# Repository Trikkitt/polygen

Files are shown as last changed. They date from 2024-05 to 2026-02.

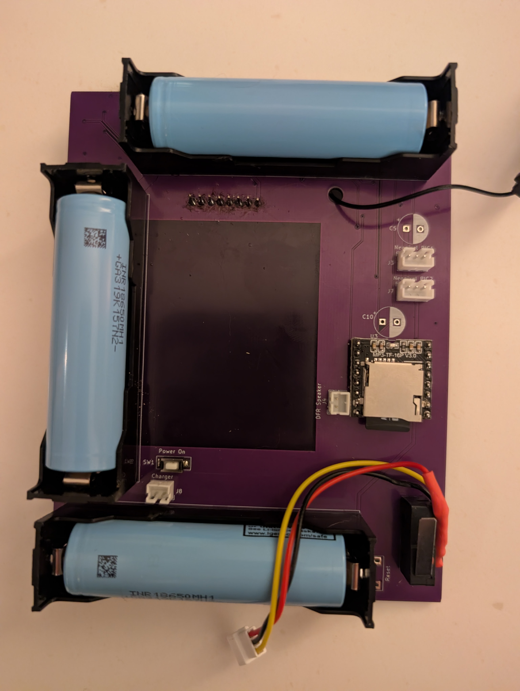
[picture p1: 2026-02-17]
PCB/PCB - Bottom.jpg

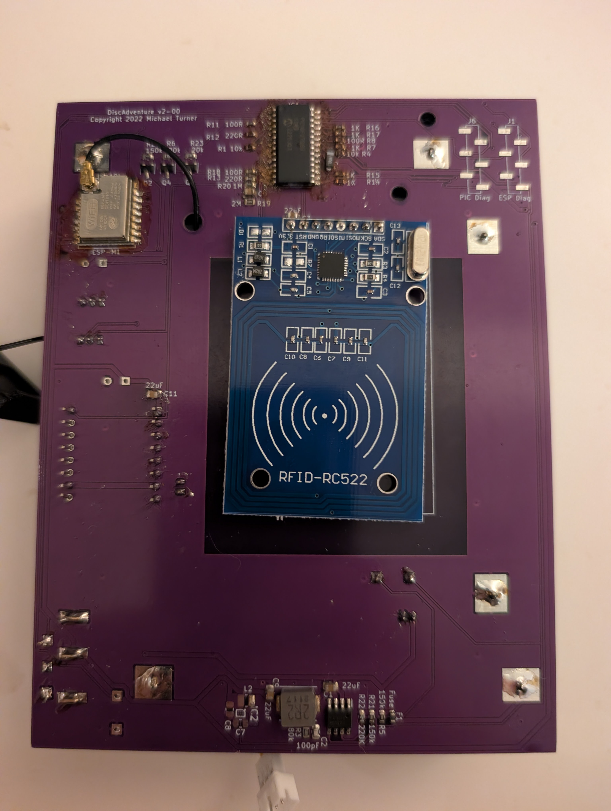
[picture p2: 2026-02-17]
PCB/PCB - Top.jpg

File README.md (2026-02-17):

The folders are as follows:

3D Models : Contains the STL files for the casing and information about the physical assembly
  
PIC : Contains the source code and compiled .HEX file for the PIC Microcontroller used by the game

Micropython : Contains the Micropyhon code used by the ESP8285 used by the game

PCB : Contains the KiCAD PCB design used in each of the game units
  
Game : Contains the primary game code including database

Sounds: The audio files played by the game units, along with some source / raw media.

The 3D model was designed using Tinkercad.  The URL for the 2024 design is https://www.tinkercad.com/things/fUl2xMWVo1S-polygen-case-2024-final and the 2025 design https://www.tinkercad.com/things/fGMrmOF5N9D-polygen-case-2025-final and this repository contains the export STL files from Tinkercad.

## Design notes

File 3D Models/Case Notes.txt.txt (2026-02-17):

The main body of the case can be printed in most materials of your choice.  I've found that Polycarbonate can be strong but will shatter if enough force is used. I don't recommend PLA because that can warp if it gets too warm.  If you're using this at a festival it can get a bit hot.

The clips should be printed in PETG.  This gives them maximum flex without snapping, they cannot be printed in polycarbonate.  Extra bits needed for the cases:

UK 2p coins (magnetic, not the older copper coins).  If you don't have access to these then you might want to consider some large washers and slightly redesigning the clips to hold them.  You could completely ignore the clips, but they really should be used to keep the upper and lower sections at the front pulled together evenly.  You could redesign to just use screws if you wanted to simplify the design.

The V2 case uses M4 threaded inserts.  You'll need 4 per case.  One in the speaker holder/cover, one in the front main body at the top where the reinforcement screws are located, and one on the antenna mount.  You'll need matching M4 bolts 16mm.

The case will print without supports on most 3D printers. Each of the main parts prints with the outward face being downwards.  For my printed I used a textured PEI bed to give it a nice finish.  I used a Bambu X1C for my prints using a multi-filament design.  The logos, URLs, etc are all loaded in separately and then merged within Bambu studio.  

There is an extra tamper switch mount.  This is optional and I haven't used them on any of my units.  It is intended to go into the top left corner of the PCB to provide two detection locations on the PCB.  It isn't really needed but if you're wanting to ensure even if the case is smashed open the tamper detection is triggered, this is the way to go.

If you want to see the finish printed case parts then please look in the assembly folder that will show you the various parts being assembled / pulled apart.

You can look at the original design on this URL.  Feel free to copy and remix it to fix anything you want to change.

https://www.tinkercad.com/things/fGMrmOF5N9D-polygen-case-2025-final

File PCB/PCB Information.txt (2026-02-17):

This PCB was designed in KiCAD and went through a few revisions, in part due to issues with supply on components in 2021/2022.  Most of the parts are readily available still, however you may struggle to find the parts for the 3.3v power supply, these were constantly appearing and dropping out of availability.  The RC522 boards are available but quality of these varies a lot, with some simply not being viable for reading anything other than the most basic MiFare Classic clone cards.  Some details about how to improve some modules is available here https://trikkitt.com/rfid-rc522-rfid-reader-modules-why-they-dont-work-and-how-to-fix-them/ but be aware some are so bad they can't be fixed.  I had to bin around 20 modules as a result.  While it mentioned the DFR299 audio modules there are very cheap clones available that I ended up using to keep costs down.  The tamper switches are optional, if you aren't going to use them either remove the code that monitors them, or link them out.  If you only need one then make sure you link the other one out or you will get problems!

Update from November 2025: The original PIC microcontroller (16LF15356) has run out of capacity as of the code base from mid-2025.  As a result all of my units have been upgraded to use 18F27Q83.  This new PIC has sufficient capacity for future code increases and isn't crazy expensive.  It does consume a little more energy as it isn't the LF version (it just isn't available on this model) and it can run at higher clock speeds. They are pin compatible, so can be used interchangeably if required, but be aware the older one has zero space and has no OTA update code.  While the 18F27Q83 has lots of capacity and the current build does contain a very basic OTA update mechanism.

The power supply chip has gone end of life.  When checking the chip was available from Farnell from limit residual stock.  Before producing these PCBs please ensure you either have purchased the chips required OR redesign the 3.3v power regulation with a new part.  Note it does include two power chips, you need only populate one of them! One turned out to be way too small to be hand soldered and was never populated or tested.  The main things are to check that any replacement supports an enable pin on the chip so that the PIC microcontroller can control the power and turn the unit off if needed.

The tamper detection switches are optional.  But if you don't use them, then be sure to link them out to avoid floating voltages triggering the tamper detection incorrectly.  The pictured tamper detection configuration uses a PCB mounted microswitch to detect removal of the back case, and it also includes a cable run to a microswitch mounted on the back of the case to detect removal of the speaker.  The red heat shrink includes a 10K Ohm resistor just in case of shorts on the microswitch, but it will work without the resistor. If you don't want this secondary switch then just link out the switch connections.

The RC522 RFID reader has the LED removed to save power (it serves no useful purpose), it also has the pullup resistor removed as the PIC always directly drives this pin, therefore there is no benefit to having this resistor and it wastes power.  The inductors are replaced (link to article above) so that it can successfully read more than just the Mifare 1k RFID cards.

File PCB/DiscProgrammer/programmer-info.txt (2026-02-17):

The programmer is a very simple PCB designed to enable connection of either a PICKit3 programmer to the main PCB to programme the PIC microcontroller or a simple 3.3v USB to serial connection for the ESP825 module.

The programmer uses pogo pins to connect to the main PCB.  Be aware that when I made this I used the battery connector to pickup the ground connection on the PCB.  A flooded battery connector can push up the pogo pin so far you don't make good contact on the remaining pins.  These really need a 3D printed case to help home it correctly.

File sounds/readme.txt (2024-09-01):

The sound files in the MP3 folder are the files stored on the MicroSD card inserted into the MP3 player inside each unit.  The file numbers are critical - they must be copied in that exact order as the game references them by index number and not filename.

The sound was generated via a few mechanisms.  The more recent ones are Azure Text to Speech.  While some other TTS services were used for the earlier voices.  The sound effects were generated via various tools and manipulated using Audacity.

https://app.audiogen.co/
https://speech.microsoft.com/portal

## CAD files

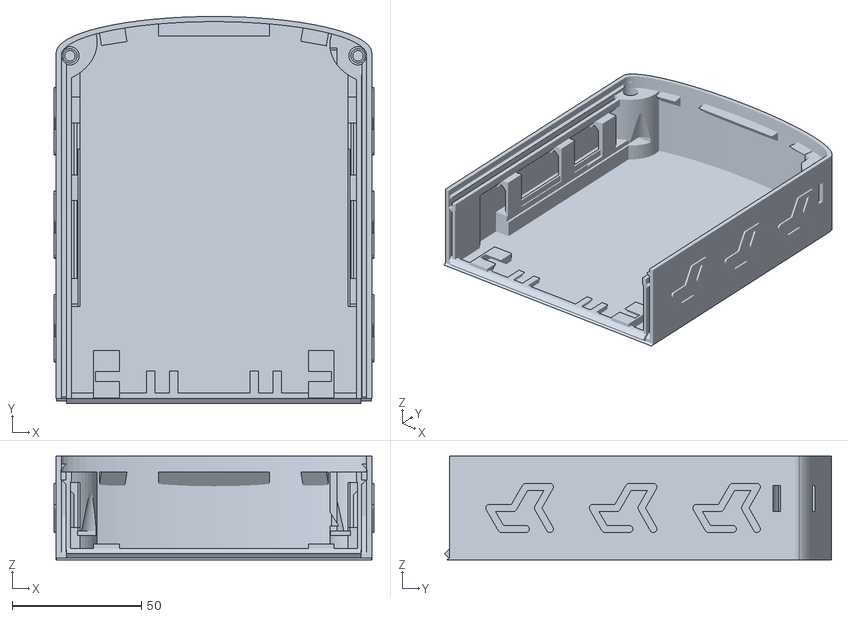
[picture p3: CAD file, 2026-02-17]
3D Models/Case V2/PolyGen Case Main Body.stl
123.7 x 149.6 x 40.0

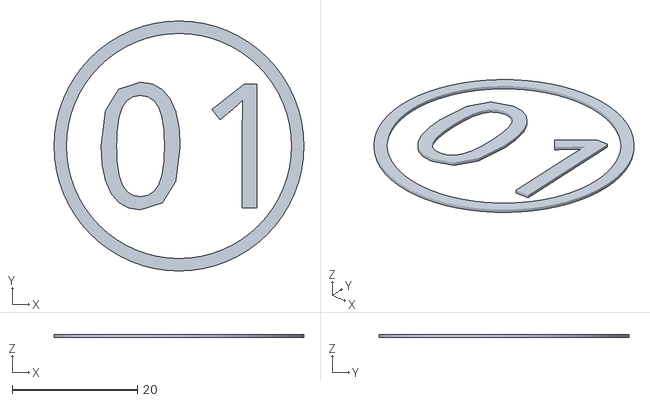
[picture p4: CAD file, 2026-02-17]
3D Models/Case V2/PolyGen Case Back Case ID 01.stl
40.0 x 40.0 x 0.5

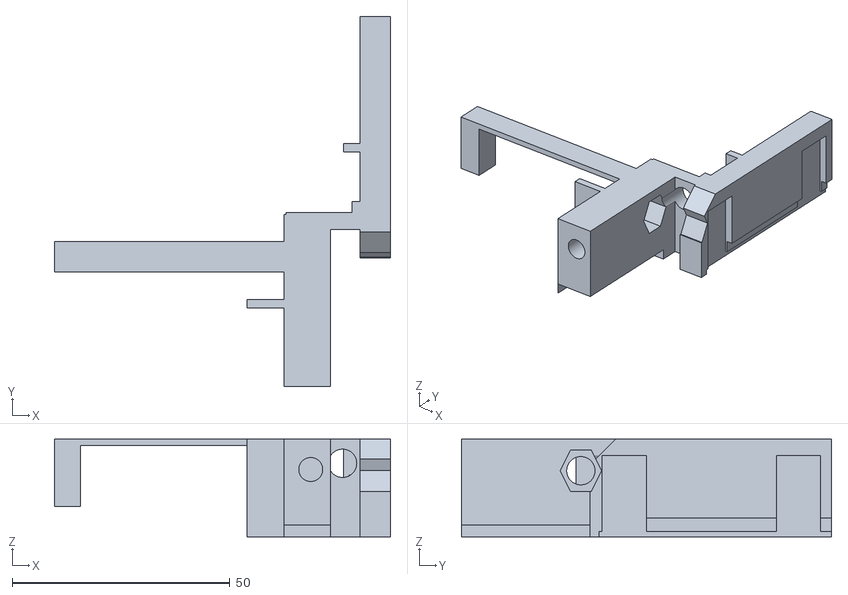
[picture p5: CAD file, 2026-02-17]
3D Models/Case V2/PolyGen Case Antenna Holder.stl
77.2 x 85.0 x 22.5

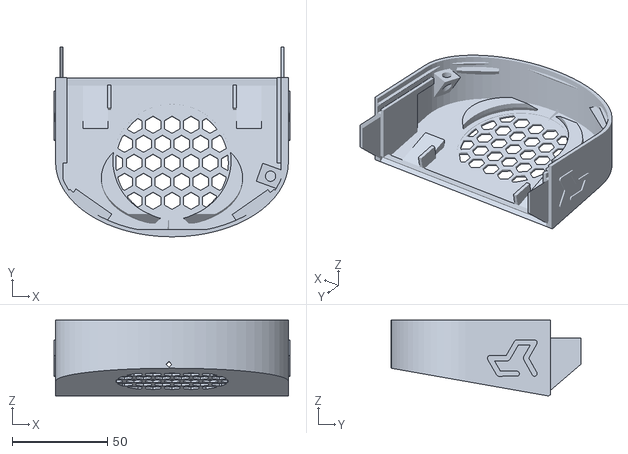
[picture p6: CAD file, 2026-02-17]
3D Models/Case V2/PolyGen Case Front Speaker Cover.stl
123.7 x 99.4 x 39.8

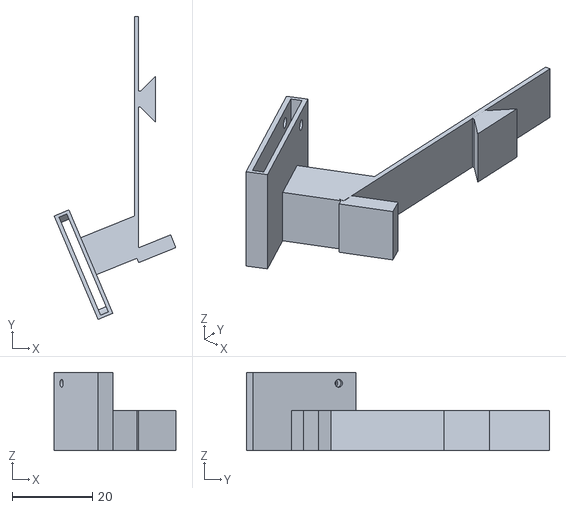
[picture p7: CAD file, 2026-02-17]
3D Models/Case V2/PolyGen Case Left Clip.stl
30.3 x 75.5 x 19.5

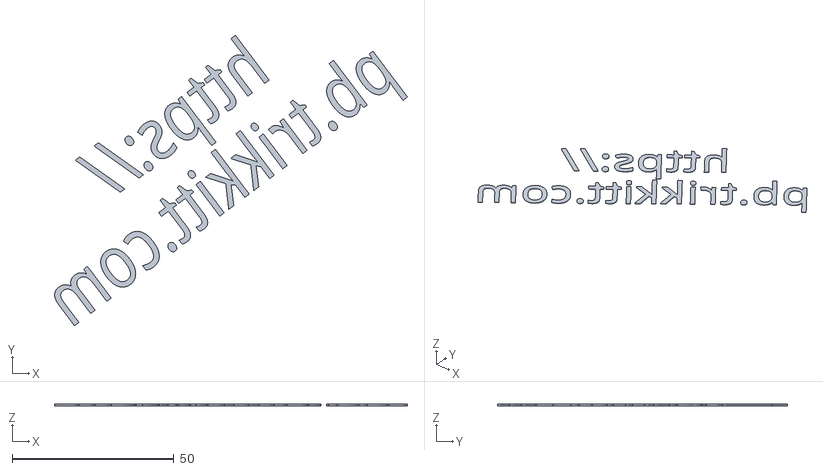
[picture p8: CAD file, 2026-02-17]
3D Models/Case V2/PolyGen Case Back URL.stl
109.0 x 89.7 x 0.5

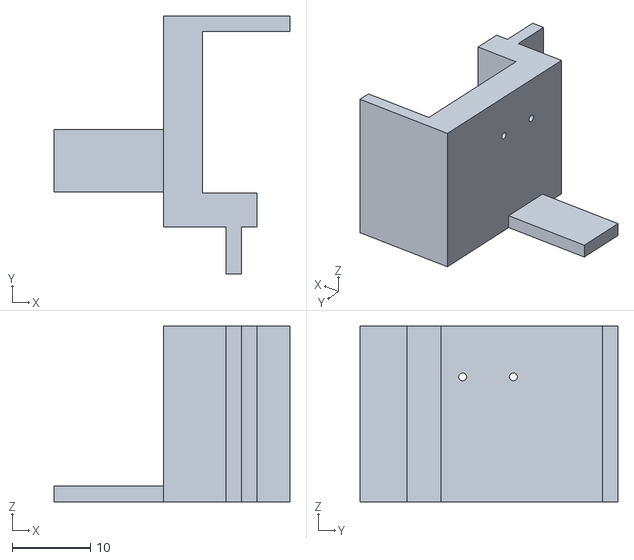
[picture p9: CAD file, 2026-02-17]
3D Models/Case V2/PolyGen Case Extra Tamper Switch Mount.stl
30.2 x 33.0 x 22.5

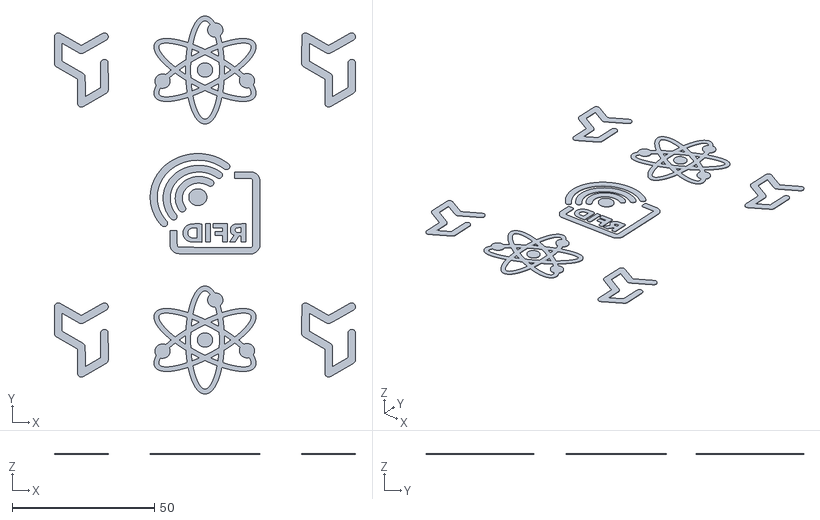
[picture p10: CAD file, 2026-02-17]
3D Models/Case V2/PolyGen Case Front Logos.stl
106.0 x 133.0 x 0.495

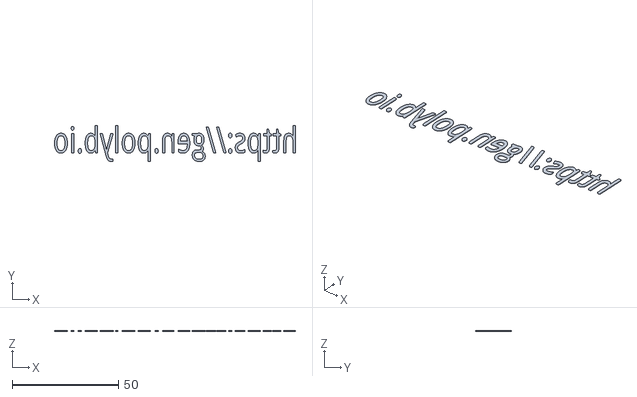
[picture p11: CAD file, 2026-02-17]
3D Models/Case V2/PolyGen Case Front URL.stl
113.4 x 17.0 x 0.5

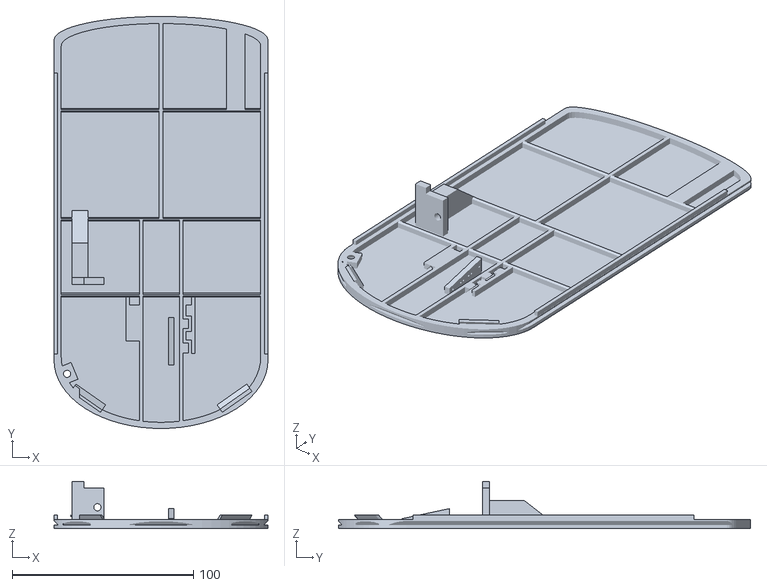
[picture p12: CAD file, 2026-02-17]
3D Models/Case V2/PolyGen Case Back Panel.stl
118.0 x 227.2 x 26.0

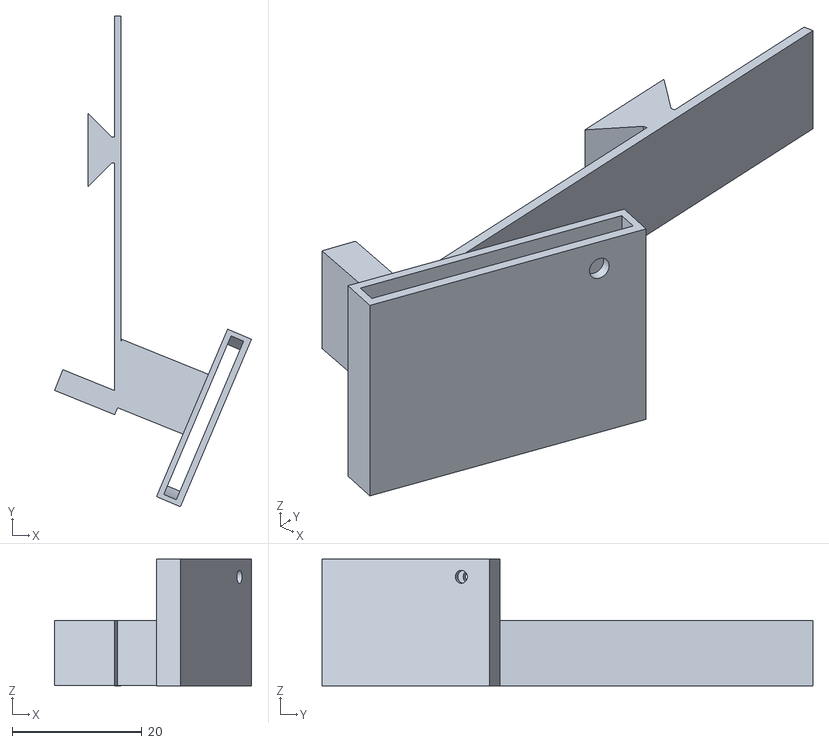
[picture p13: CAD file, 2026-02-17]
3D Models/Case V2/PolyGen Case Right Clip.stl
30.3 x 75.5 x 19.5

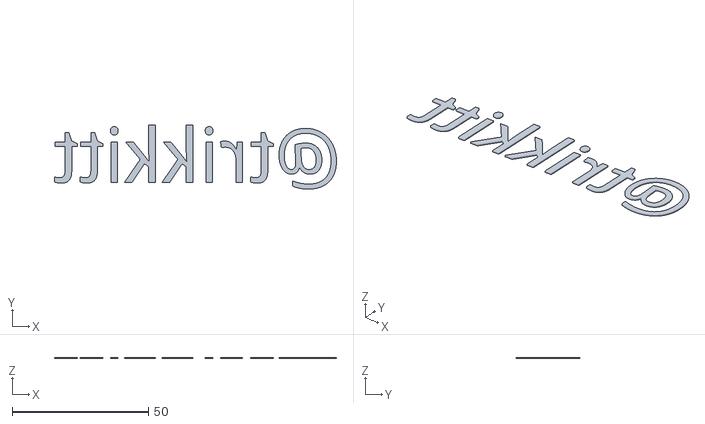
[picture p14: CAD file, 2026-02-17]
3D Models/Case V2/PolyGen Case Twitter Name.stl
103.3 x 23.6 x 0.5

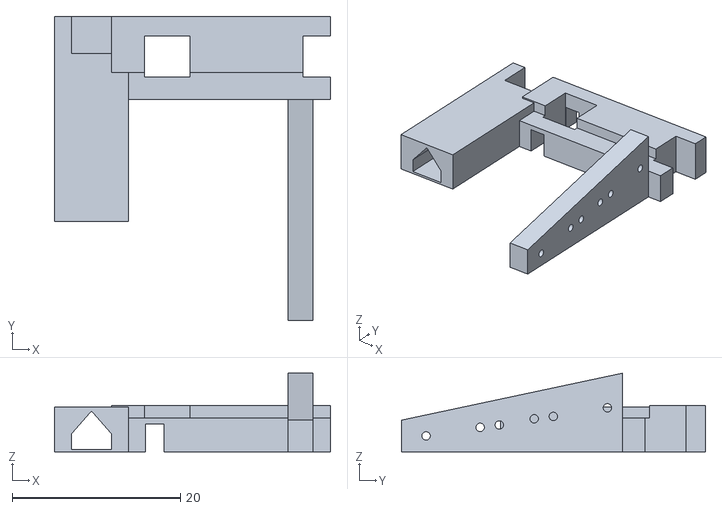
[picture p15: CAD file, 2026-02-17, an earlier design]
3D Models/Case V1/PolyGen Case Tamper Switch Mount and USB Delete.stl
32.8 x 36.2 x 9.34

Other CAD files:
3D Models/Case V1/PolyGen Case Main Body.stl
3D Models/Case V1/PolyGen Case Back URL.stl
3D Models/Case V1/PolyGen Case Left Clip.stl
3D Models/Case V1/PolyGen Case Front URL.stl
3D Models/Case V1/PolyGen Case Front Speaker Cover.stl
3D Models/Case V1/PolyGen Case Antenna Holder.stl
3D Models/Case V1/PolyGen Case Back Panel.stl
3D Models/Case V1/PolyGen Case Front Logos.stl
3D Models/Case V1/PolyGen Case Right Clip.stl
3D Models/Case V1/PolyGen Case Twitter Name.stl

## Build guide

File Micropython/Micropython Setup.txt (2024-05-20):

This code has been written for Micropython v1.18 on 2022-01-17.  It has been compiled using the cross-compiler as the code is too large for the ESP8285 to run uncompiled.  If you need to target a different version of Micropython then you'll need to run the matched cross-compiler for the version you have used.  This version was used because when the code was written it was the latest version available.  Newer versions are available but due to time constraints it was not possible to update to the latest version of Micropython.  

Using a blank Micropython installation on the ESP8285 the following commands should be run to prepare it.

import network
import utime
from ubinascii import unhexlify
wifi_SSID='<yourSSID>'
wifi_PSK='<yourPSK>'
sta_if = network.WLAN(network.STA_IF)
sta_if.active(True)
sta_if.connect(wifi_SSID,wifi_PSK)

Then wait for the wifi to connect.  Then run the following commands:

import upip
upip.install('micropython-urequests')
upip.install('micropython-umqtt.simple')

Once completed you can now copy the .mpy files across along with the main.py that causes the module DiscCode to run automatically at bootup.

For reference the ESP8285 need a specific commandline to flash the firmware:
esptool.py.exe --port COM3 --baud 115200 write_flash --flash_size=detect -fm dout 0 ESP8266_GENERIC-FLASH_1M-20220117-v1.18.bin

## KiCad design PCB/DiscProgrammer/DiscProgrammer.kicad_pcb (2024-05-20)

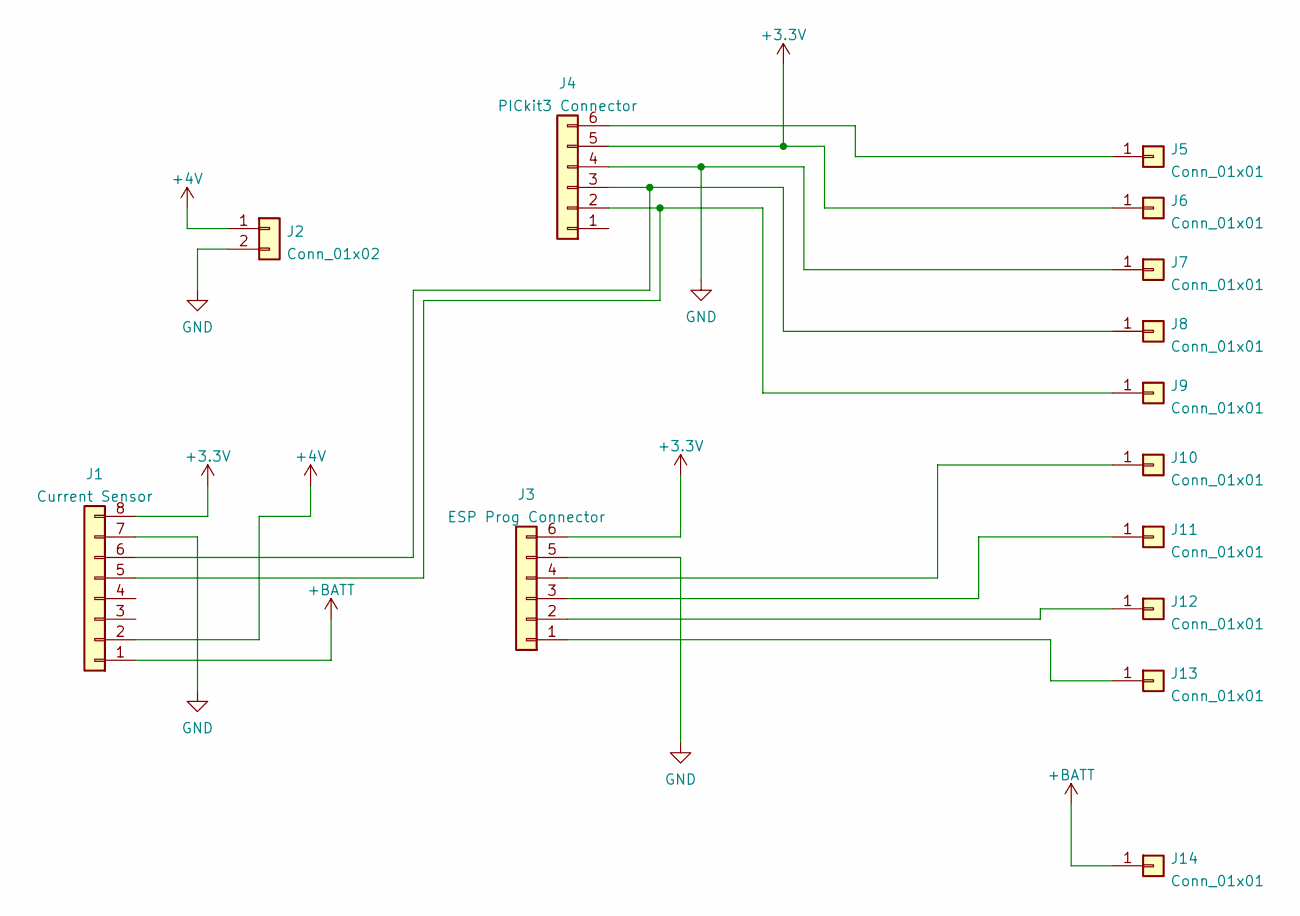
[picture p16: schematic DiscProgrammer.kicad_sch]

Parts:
J1: Current Sensor; PinHeader_1x08_P2.54mm_Vertical
J2: Conn_01x02; JST_PH_B2B-PH-K_1x02_P2.00mm_Vertical
J3: ESP Prog Connector; PinHeader_1x06_P2.54mm_Vertical
J4: PICkit3 Connector; PinHeader_1x06_P2.54mm_Vertical
J5, J6, J7, J8, J9, J10, J11, J12, J13, J14: Conn_01x01; Pin_D1.0mm_L10.0mm

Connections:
+3V3: J1.8, J3.6, J4.5, J6.1
+4V: J1.2, J2.1
+BATT: J1.1, J14.1
GND: J1.7, J2.2, J3.5, J4.4, J7.1
unnamed: J1.5, J4.2, J9.1
unnamed: J1.6, J4.3, J8.1
unnamed: J4.6, J5.1
unnamed: J3.4, J10.1
unnamed: J3.3, J11.1
unnamed: J3.2, J12.1
unnamed: J3.1, J13.1

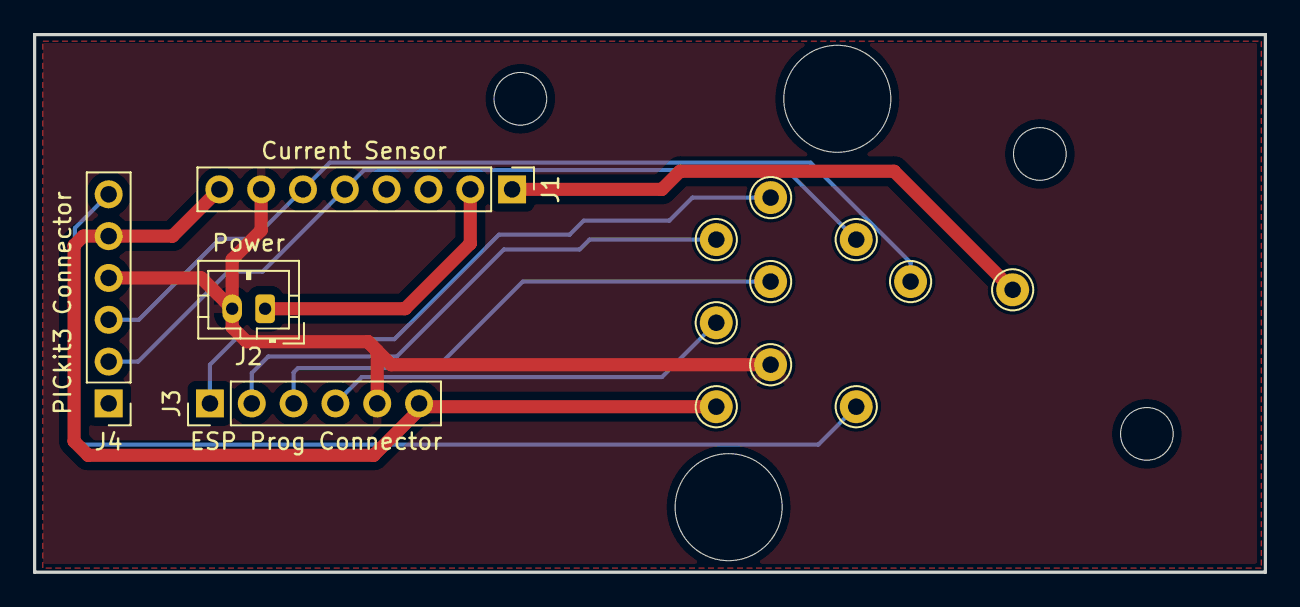
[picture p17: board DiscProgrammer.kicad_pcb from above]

Board: 2 copper layers, 74.8 x 32.6 mm, 17 parts (0 on the bottom side), 11 nets.

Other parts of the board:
H1, H1#2: Orientation Guide 2; MountingHole_3.2mm_M3_DIN965
H2: Orientation Guide 1; MountingHole_3.2mm_M3_DIN965

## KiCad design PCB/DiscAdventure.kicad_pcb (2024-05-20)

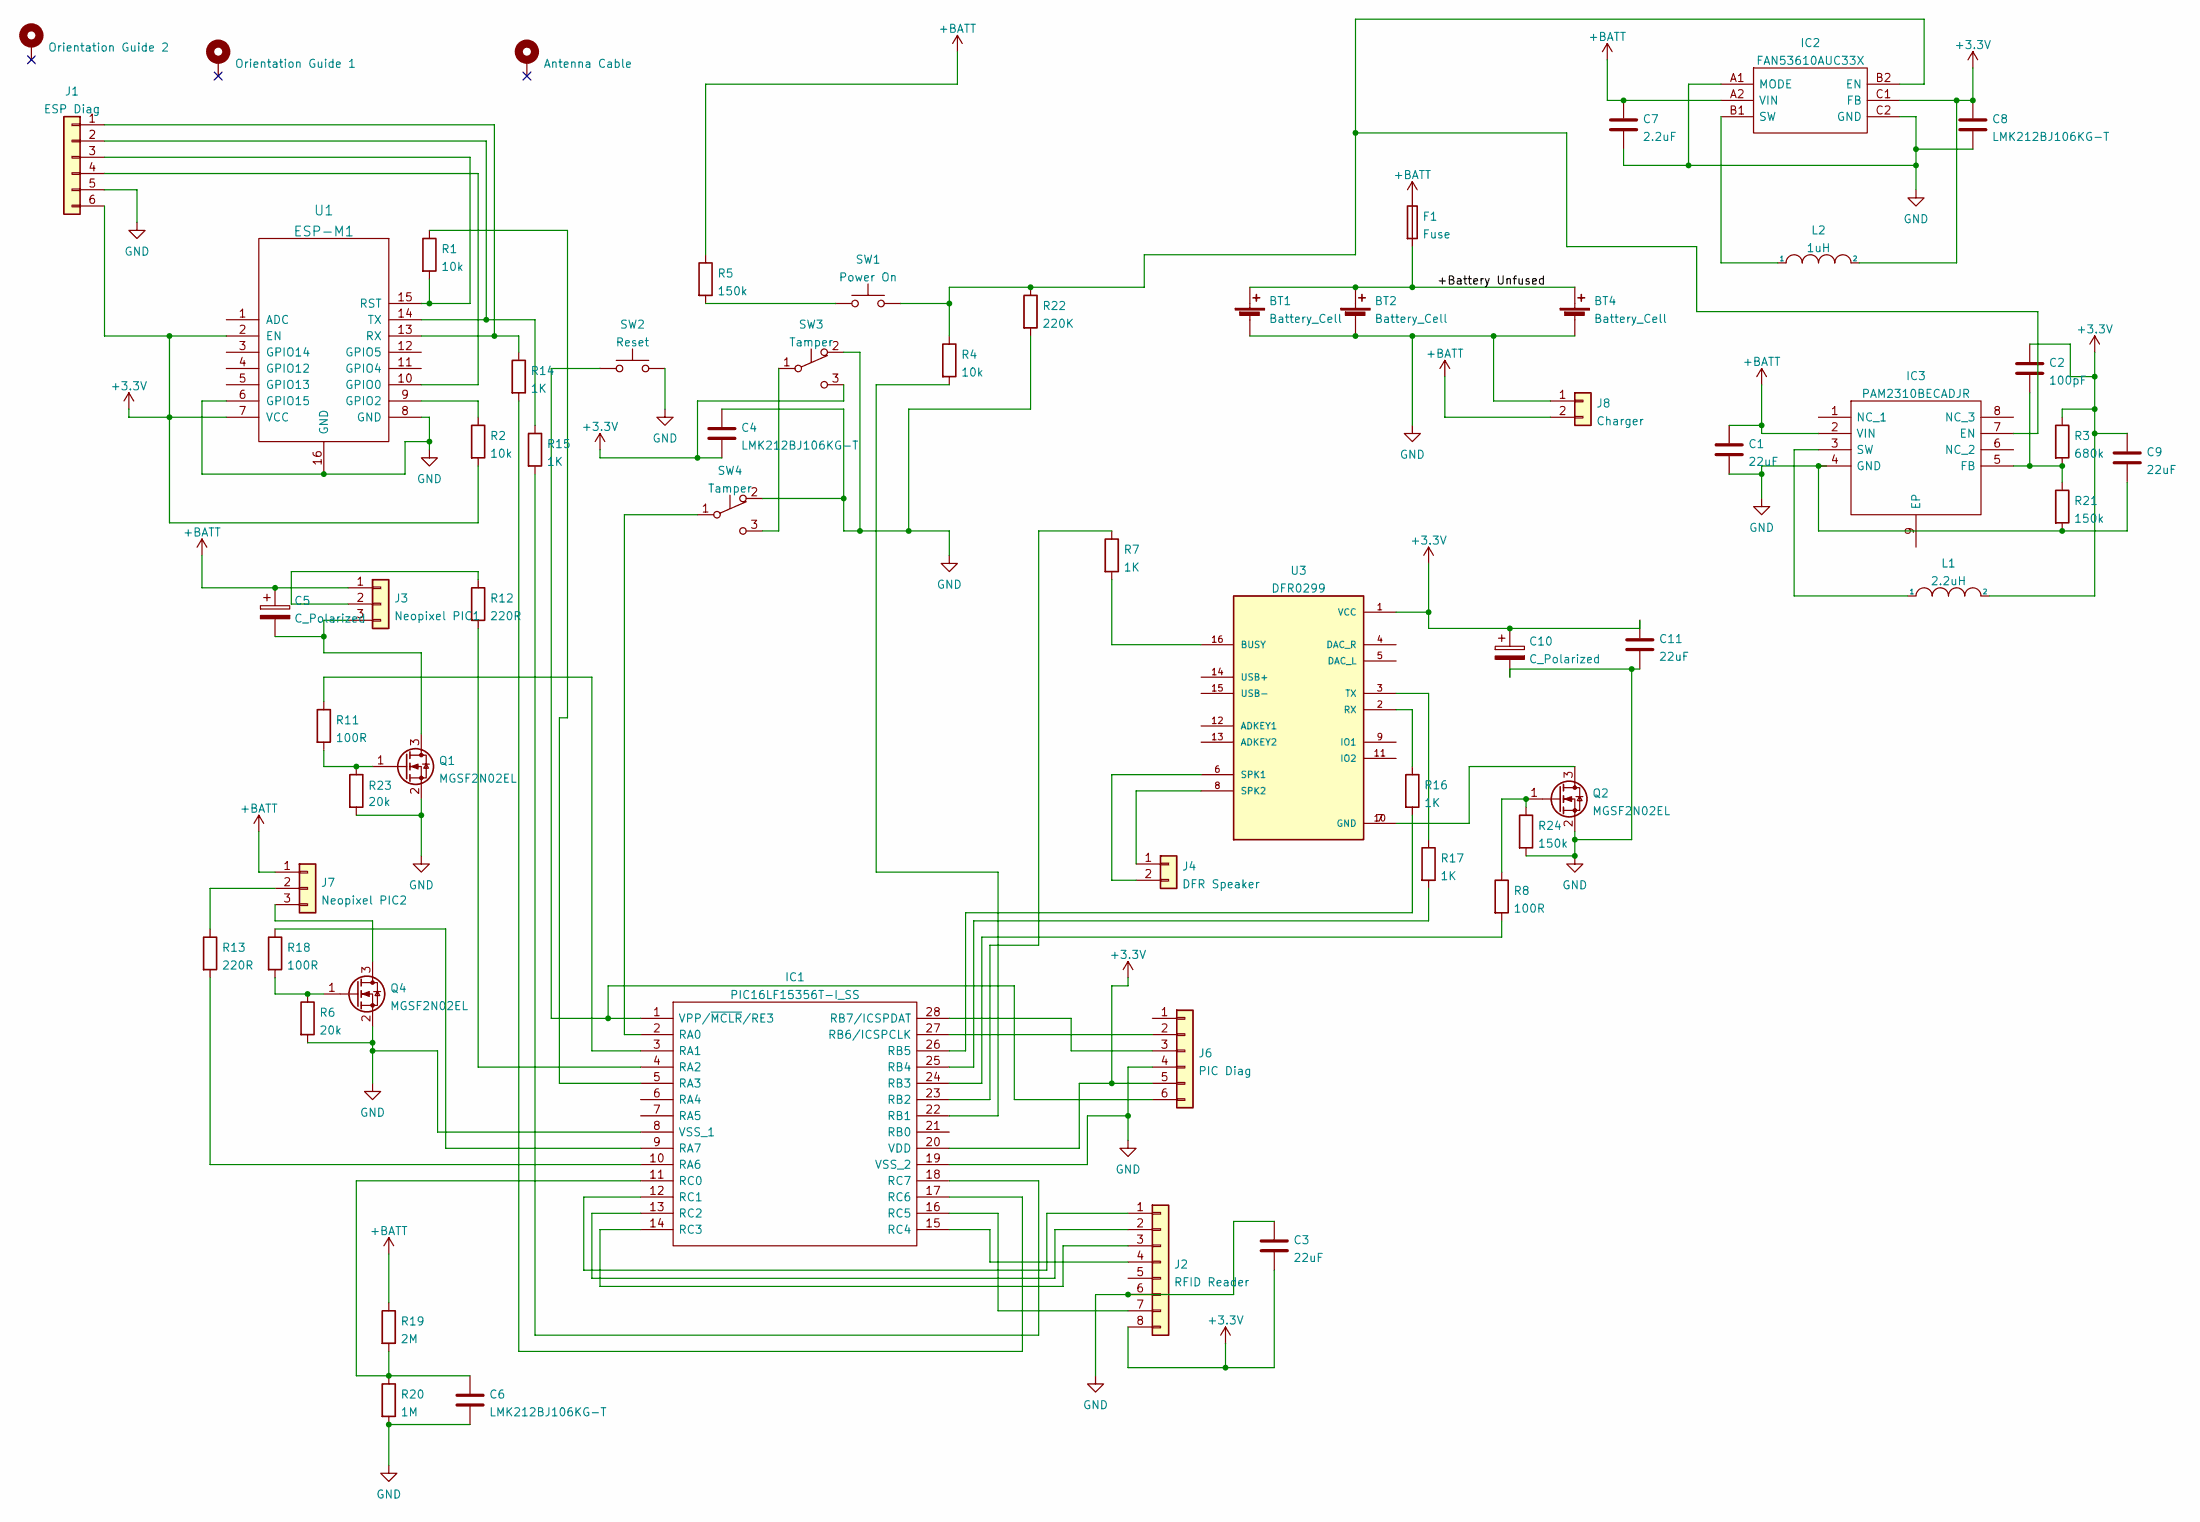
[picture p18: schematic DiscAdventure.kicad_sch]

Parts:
BT1, BT2, BT4: Battery_Cell; BatteryHolder_1x18650_TH
C1, C3, C9, C11: 22uF; C_0805_2012Metric
C2: 100pF; C_0805_2012Metric
C4, C6, C8: LMK212BJ106KG-T; C_0805_2012Metric
C5, C10: C_Polarized; CP_Radial_D8.0mm_P3.80mm
C7: 2.2uF; C_0805_2012Metric
F1: Fuse; Fuse_0603_1608Metric
H1: Orientation Guide 2; MountingHole_3.2mm_M3_DIN965
H2: Orientation Guide 1; MountingHole_3.2mm_M3_DIN965
H3: Antenna Cable; MountingHole_3.7mm
IC1: PIC16LF15356T-I_SS; SOIC-28W_7.5x17.9mm_P1.27mm; Mouser Part Number 579-IC16LF15356TI/SS
IC2: FAN53610AUC33X; BGA6C40P2X3_86X116X62; Mouser Part Number 512-FAN53610AUC33X
IC3: PAM2310BECADJR; SOIC127P600X163-9N; Mouser Part Number 621-PAM2310BECADJR
J1: ESP Diag; PinHeader_1x06_P2.54mm_Vertical_SMD_Pin1Left
J2: RFID Reader; PinHeader_1x08_P2.54mm_Vertical
J3: Neopixel PIC1; JST_PH_B3B-PH-K_1x03_P2.00mm_Vertical
J4: DFR Speaker; JST_PH_B2B-PH-K_1x02_P2.00mm_Vertical
J6: PIC Diag; PinHeader_1x06_P2.54mm_Vertical_SMD_Pin1Left
J7: Neopixel PIC2; JST_PH_B3B-PH-K_1x03_P2.00mm_Vertical
J8: Charger; JST_PH_B2B-PH-K_1x02_P2.00mm_Vertical
L1: 2.2uH; INDPM7466X300N
L2: 1uH; L_1008_2520Metric
Q1, Q2, Q4: MGSF2N02EL; SOT-23
R1, R2, R4: 10k; R_0603_1608Metric
R3: 680k; R_0603_1608Metric
R5, R21, R24: 150k; R_0603_1608Metric
R6, R23: 20k; R_0603_1608Metric
R7, R14, R15, R16, R17: 1K; R_0603_1608Metric
R8, R11, R18: 100R; R_0603_1608Metric
R12, R13: 220R; R_0603_1608Metric
R19: 2M; R_0603_1608Metric
R20: 1M; R_0603_1608Metric
R22: 220K; R_0603_1608Metric
SW1: Power On; SW_DIP_SPSTx01_Piano_10.8x4.1mm_W7.62mm_P2.54mm
SW2: Reset; SW_DIP_SPSTx01_Piano_10.8x4.1mm_W7.62mm_P2.54mm
SW3: Tamper; Microswitch TH
SW4: Tamper; Microswitch TH 90 Degree Right
U1: ESP-M1
U3: DFR0299; MODULE_DFR0299

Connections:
+3V3: C2.1, C3.2, C4.2, C8.1, C9.1, C10.1, C11.1, IC1.20 (VDD), IC2.C1 (FB), J1.6, J2.8, J6.5, L1.2, L2.2, R2.2, R3.1, SW3.3 (C), U1.2 (EN), U1.7 (VCC), U3.1 (VCC)
+BATT: C1.1, C5.1, C7.1, F1.1, IC2.A2 (VIN), IC3.2 (VIN), J3.1, J7.1, J8.2, R5.1, R19.1
/+Battery Unfused: BT1.1 (+), BT2.1 (+), BT4.1 (+), F1.2
GND: BT1.2 (-), BT2.2 (-), BT4.2 (-), C1.2, C3.1, C4.1, C6.2, C7.2, C8.2, C9.2, C10.2, C11.2, IC1.8 (VSS_1), IC1.19 (VSS_2), IC2.A1 (MODE), IC2.C2 (GND), IC3.4 (GND), J1.5, J2.6, J6.4, J8.1, Q1.2 (S), Q2.2 (S), Q4.2 (S), R6.2, R20.2, R21.2, R22.2, R23.2, R24.2, SW2.2, SW3.2 (A), SW4.2 (A), U1.6 (GPIO15), U1.8 (GND), U1.16 (GND)
unnamed: C2.2, IC3.5 (FB), R3.2, R21.1
unnamed: C5.2, J3.3, Q1.3 (D)
unnamed: C6.1, IC1.11 (RC0), R19.2, R20.1
unnamed: IC1.1 (VPP/~MCLR/RE3), J6.6, SW2.1
unnamed: IC1.2 (RA0), SW4.1 (B)
unnamed: IC1.3 (RA1), R11.1
unnamed: IC1.4 (RA2), R12.2
unnamed: IC1.5 (RA3), R1.1
unnamed: IC1.9 (RA7), R18.1
unnamed: IC1.10 (RA6), R13.2
unnamed: IC1.12 (RC1), J2.1
unnamed: IC1.13 (RC2), J2.2
unnamed: IC1.14 (RC3), J2.3
unnamed: IC1.15 (RC4), J2.4
unnamed: IC1.16 (RC5), J2.7
unnamed: IC1.17 (RC6), R14.2
unnamed: IC1.18 (RC7), R15.2
unnamed: IC1.22 (RB1), R4.2
unnamed: IC1.23 (RB2), R7.1
unnamed: IC1.24 (RB3), R8.2
unnamed: IC1.25 (RB4), R17.2
unnamed: IC1.26 (RB5), R16.2
unnamed: IC1.27 (RB6/ICSPCLK), J6.2
unnamed: IC1.28 (RB7/ICSPDAT), J6.3
unnamed: IC2.B1 (SW), L2.1
unnamed: IC2.B2 (EN), IC3.7 (EN), R4.1, R22.1, SW1.2
unnamed: IC3.3 (SW), L1.1
unnamed: J1.1, R14.1, U1.13 (RX)
unnamed: J1.2, R15.1, U1.14 (TX)
unnamed: J1.3, R1.2, U1.15 (RST)
unnamed: J1.4, U1.10 (GPIO0)
unnamed: J3.2, R12.1
unnamed: J4.1, U3.8 (SPK2)
unnamed: J4.2, U3.6 (SPK1)
unnamed: J7.2, R13.1
unnamed: J7.3, Q4.3 (D)
unnamed: Q1.1 (G), R11.2, R23.1
unnamed: Q2.1 (G), R8.1, R24.1
unnamed: Q2.3 (D), U3.7 (GND), U3.10 (GND)
unnamed: Q4.1 (G), R6.1, R18.2
unnamed: R2.1, U1.9 (GPIO2)
unnamed: R5.2, SW1.1
unnamed: R7.2, U3.16 (BUSY)
unnamed: R16.1, U3.2 (RX)
unnamed: R17.1, U3.3 (TX)
unnamed: SW3.1 (B), SW4.3 (C)

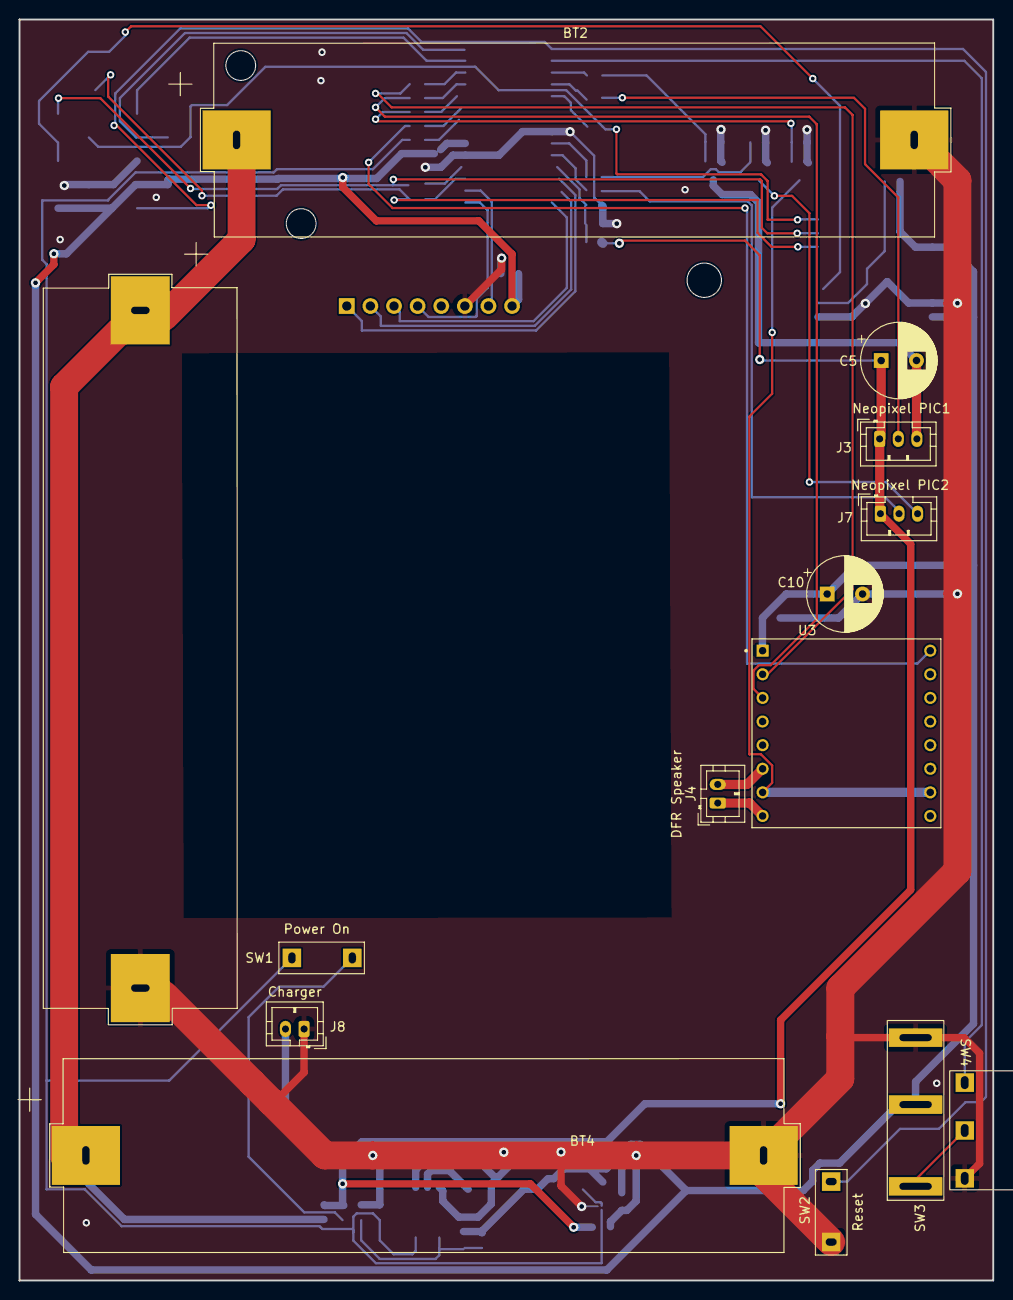
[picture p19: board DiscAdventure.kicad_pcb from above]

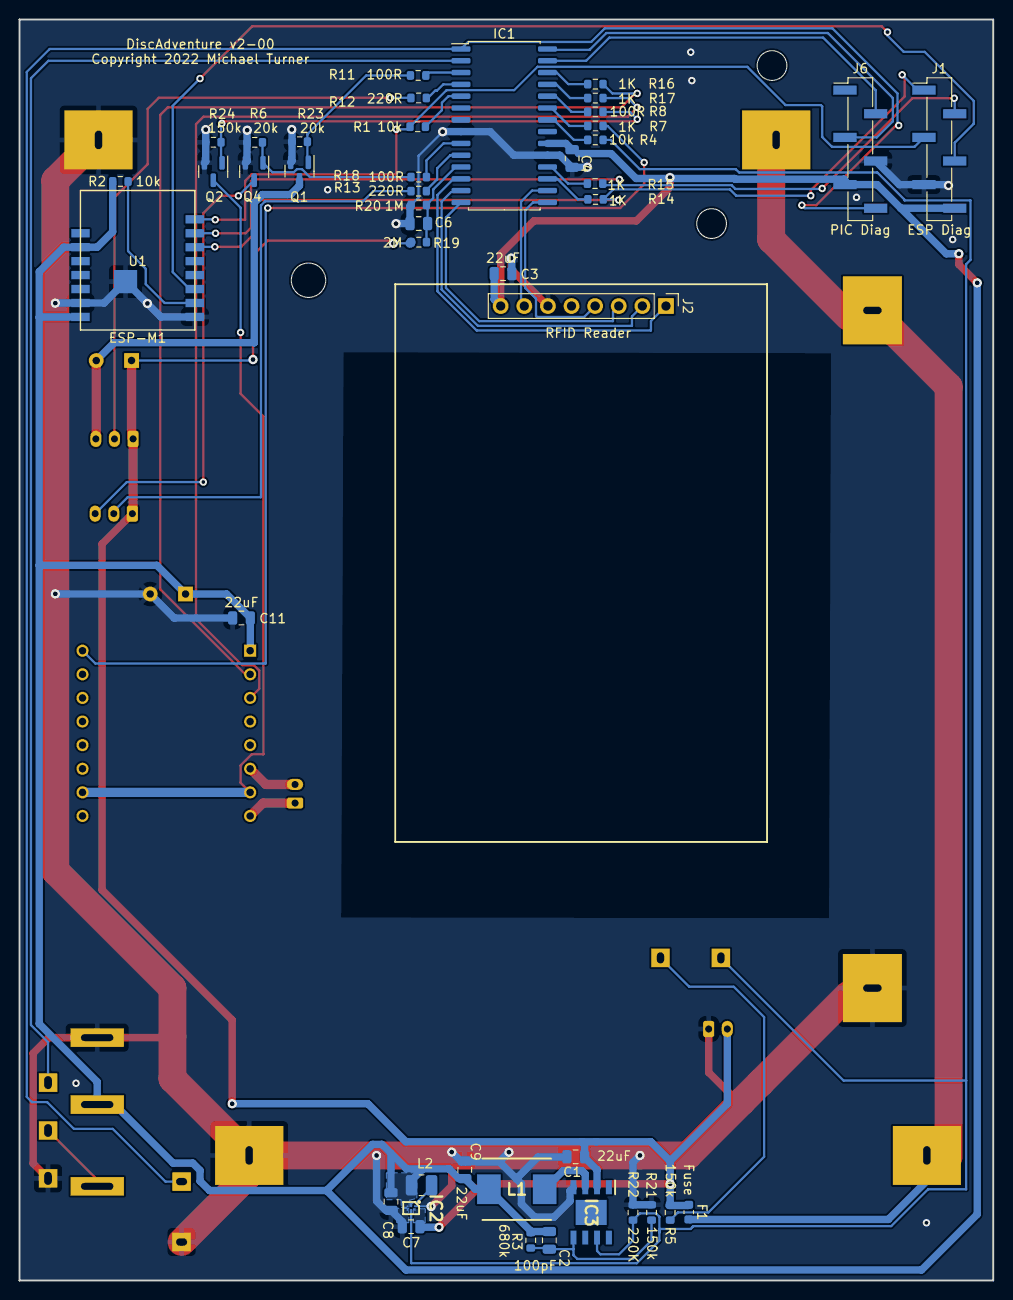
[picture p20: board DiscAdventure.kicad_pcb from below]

Board: 2 copper layers, 104.7 x 135.6 mm, 61 parts (44 on the bottom side), 50 nets.

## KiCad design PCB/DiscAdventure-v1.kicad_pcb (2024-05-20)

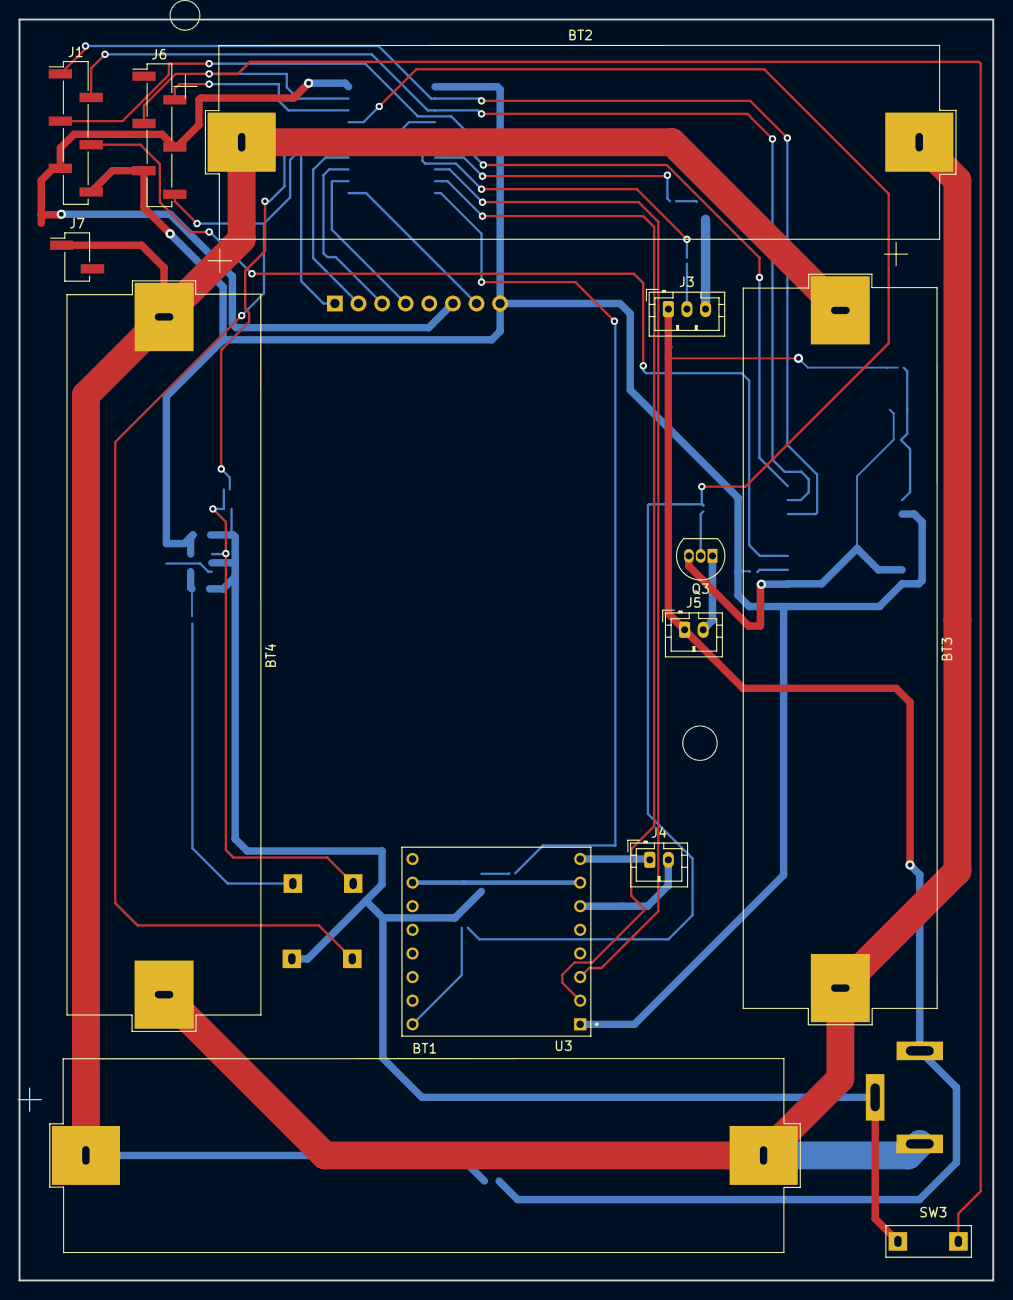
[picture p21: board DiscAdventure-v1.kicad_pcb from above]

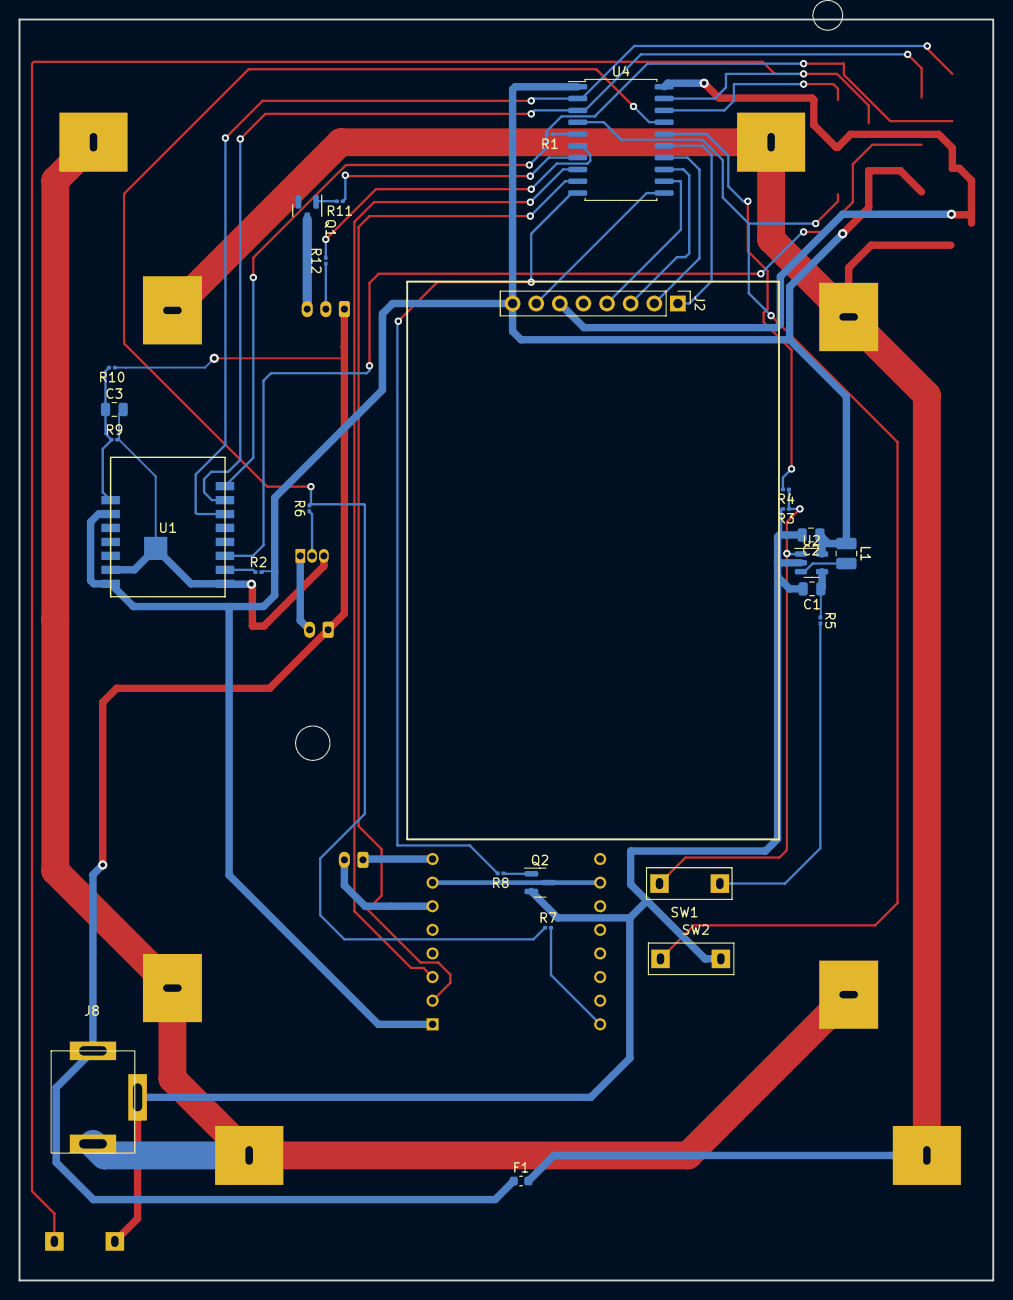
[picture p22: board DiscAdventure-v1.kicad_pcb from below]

Board: 2 copper layers, 104.7 x 135.6 mm, 42 parts (26 on the bottom side), 40 nets.

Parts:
BT1, BT2, BT3, BT4: Battery_Cell; BatteryHolder_1x18650_TH
C1, C2, C3: LMK212BJ106KG-T; C_0805_2012Metric
F1: Fuse; Fuse_0603_1608Metric
H1: Orientation Guide 2; MountingHole_3.2mm_M3_DIN965
H2: Orientation Guide 1; MountingHole_3.2mm_M3_DIN965
H3: Antenna Cable; MountingHole_3.7mm
J1: ESP Diag; PinHeader_1x06_P2.54mm_Vertical_SMD_Pin1Left
J2: RFID Reader; PinHeader_1x08_P2.54mm_Vertical
J3: Neopixel; JST_PH_B3B-PH-K_1x03_P2.00mm_Vertical
J4: DFR Speaker; JST_PH_B2B-PH-K_1x02_P2.00mm_Vertical
J5: PWM Speaker; JST_PH_B2B-PH-K_1x02_P2.00mm_Vertical
J6: PIC Diag; PinHeader_1x06_P2.54mm_Vertical_SMD_Pin1Left
J7: Conn_01x01; PinHeader_1x02_P2.54mm_Vertical_SMD_Pin1Left
J8: Barrel_Jack_Switch; PJ-028B Barrel Connector
L1: MAKK2520T4R7M; L_1008_2520Metric
Q1, Q2: MGSF2N02EL; SOT-23
Q3: BC549; TO-92_Inline
R1, R2, R4: 10k; R_0201_0603Metric
R3, R5: 20k; R_0201_0603Metric
R6, R12: 220R; R_0201_0603Metric
R7, R8, R11: 100R; R_0201_0603Metric
R9: 2M; R_0201_0603Metric
R10: 10M; R_0201_0603Metric
SW1: Power On; SW_DIP_SPSTx01_Piano_10.8x4.1mm_W7.62mm_P2.54mm
SW2: Reset; SW_DIP_SPSTx01_Piano_10.8x4.1mm_W7.62mm_P2.54mm
SW3: Tamper Detect; SW_DIP_SPSTx01_Piano_10.8x4.1mm_W7.62mm_P2.54mm
U1: ESP-M1
U2: PAM2301CAAB330; TSOT-23-5
U3: DFR0299; MODULE_DFR0299
U4: PIC16F15345-I/SO; SOIC-20W_7.5x12.8mm_P1.27mm

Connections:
+3V3: C2.1, J1.6, J2.8, J6.5, L1.1, R2.2, U1.2 (EN), U1.7 (VCC), U2.5 (VOUT), U3.1 (VCC), U4.1 (VDD)
+BATT: C1.1, F1.1, J3.1, J5.1, J8.1, R5.1, R10.1, U2.4 (VIN)
/+Battery Unfused: BT1.1 (+), BT2.1 (+), BT3.1 (+), BT4.1 (+), F1.2, J7.1
/-Battery Unfused: BT1.2 (-), BT2.2 (-), BT3.2 (-), BT4.2 (-), J8.2
GND: C1.2, C2.2, C3.2, J1.5, J2.6, J6.4, J8.3, Q1.2 (S), Q2.2 (S), Q3.3 (E), R3.2, R9.2, SW2.2, SW3.1, U1.6 (GPIO15), U1.8 (GND), U1.16 (GND), U2.2 (GND), U4.20 (Vss)
unnamed: C3.1, R9.1, R10.2, U1.1 (ADC)
unnamed: J1.1, U1.13 (RX), U4.2 (RA5)
unnamed: J1.2, U1.14 (TX), U4.3 (RA4)
unnamed: J1.3, R1.2, U1.15 (RST)
unnamed: J1.4, U1.10 (GPIO0)
unnamed: J2.1, U4.15 (RC1)
unnamed: J2.2, U4.14 (RC2)
unnamed: J2.3, U4.13 (RB4)
unnamed: J2.4, U4.12 (RB5)
unnamed: J2.7, U4.11 (RB6)
unnamed: J3.2, R12.1
unnamed: J3.3, Q1.3 (D)
unnamed: J4.1, U3.8 (SPK2)
unnamed: J4.2, U3.6 (SPK1)
unnamed: J5.2, Q3.1 (C)
unnamed: J6.2, U4.18 (RA1/ICSPCLK)
unnamed: J6.3, SW3.2, U4.19 (RA0/ICSPDAT)
unnamed: J6.6, SW2.1, U4.4 (Vpp/MCLR/RA3)
unnamed: L1.2, U2.3 (SW)
unnamed: Q1.1 (G), R11.2
unnamed: Q2.1 (G), R8.1
unnamed: Q2.3 (D), U3.7 (GND), U3.10 (GND)
unnamed: Q3.2 (B), R6.1
unnamed: R1.1, U4.5 (RC5)
unnamed: R2.1, U1.9 (GPIO2)
unnamed: R3.1, R4.1, SW1.2, U2.1 (EN)
unnamed: R4.2, U4.16 (RC0)
unnamed: R5.2, SW1.1
unnamed: R6.2, R7.1, U4.17 (RA2)
unnamed: R7.2, U3.16 (BUSY)
unnamed: R8.2, U4.10 (RB7)
unnamed: R11.1, U4.7 (RC3)
unnamed: R12.2, U4.6 (RC4)
unnamed: U3.2 (RX), U4.9 (RC7)
unnamed: U3.3 (TX), U4.8 (RC6)

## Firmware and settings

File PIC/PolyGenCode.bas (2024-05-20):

;-------------------------------------------------------------------------------
;**** Added by Fuse Configurator ****
; Use the Fuse Configurator plug-in to change these settings

Device = 16F15356

Config1 FEXTOSC_OFF, RSTOSC_HFINT32, CLKOUTEN_OFF, CSWEN_ON, FCMEN_ON
Config2 MCLRE_OFF, PWRTE_OFF, LPBOREN_OFF, BOREN_ON, BORV_LO, ZCD_OFF, PPS1WAY_ON, STVREN_ON
Config3 WDTCPS_WDTCPS_31, WDTE_SWDTEN, WDTCWS_WDTCWS_7, WDTCCS_LFINTOSC
Config4 BBSIZE_BB512, BBEN_OFF, SAFEN_OFF, WRTAPP_ON, WRTB_ON, WRTC_ON, WRTSAF_ON, LVP_ON
Config5 CP_ON


;Config1 FEXTOSC_OFF, RSTOSC_HFINT32, CLKOUTEN_OFF, CSWEN_ON, FCMEN_ON
;Config2 MCLRE_OFF, PWRTE_OFF, LPBOREN_OFF, BOREN_ON, BORV_LO, ZCD_OFF, PPS1WAY_ON, STVREN_ON
;Config3 WDTCPS_WDTCPS_31, WDTE_SWDTEN, WDTCWS_WDTCWS_7, WDTCCS_LFINTOSC
;Config4 BBSIZE_BB512, BBEN_OFF, SAFEN_OFF, WRTAPP_ON, WRTB_ON, WRTC_ON, WRTSAF_ON, LVP_ON
;Config5 CP_OFF

;**** End of Fuse Configurator Settings ****
;-------------------------------------------------------------------------------

  Xtal = 32
  All_Digital = TRUE    ' Set PORTA and PORTC to all digital
  
  Declare Optimiser_Level = 0
  Declare Watchdog = Off


' Breadboard assignments

  ' PORTA0 / ICSPDAT = Serial Diag In
  ' PORTA1 / ICSPCLK = Serial Diag Out
  ' PORTA2
  ' PORTA3 / MCLR
  ' PORTA4  = Serial in from WiFi
  ' PORTA5  = Serial out to WiFi
  ' PORTB4  = SPI Out
  ' PORTB5  = SPI In
  ' PORTB6  = RFID Reset
  ' PORTB7
  ' PORTC0  = Battery voltage
  ' PORTC1  = SPI Select
  ' PORTC2  = SPI Clock
  ' PORTC3  = Serial in from DFR
  ' PORTC4  = Serial out to DFR
  ' PORTC5  = WiFi Reset
  ' PORTC6  = DFRPower
  ' PORTC7  = DFR Busy
  

  ' Main PCB assignments
  Seed $0345

  Symbol SPIRFIDSelect=PORTC.1
  Symbol SPIClk=PORTC.2
  Symbol SPIOut=PORTC.3
  Symbol SPIIn=PORTC.4
  Symbol RFIDShutdown=PORTC.5
  Symbol BF=SSP1STAT.0
  
  Symbol SerialOutDiag=PORTB.6
  Symbol SerialInDiag=PORTB.7   
  
  Symbol SerialOutDFR=PORTB.5
  Symbol SerialInDFR=PORTB.4
  Symbol DFRPower=PORTB.3
  Symbol DFRBusy=PORTB.2
  
  Symbol TamperSwitch=PORTA.0
  Symbol NeoPixelPower1=PORTA.1
  Symbol NeoPixelOut1=PORTA.2
  Symbol NeoPixelPower2=PORTA.7
  Symbol NeoPixelOut2=PORTA.6
  
  Symbol WIFIReset=PORTA.3
  
  Symbol VoltageSensor=PORTC.0
  
  Symbol PowerControl=PORTB.1
  
  Symbol SerialOutWiFi=PORTC.6
  Symbol SerialInWiFi=PORTC.7

  Symbol RecentCaptureValue = 6
  
  On_Hardware_Interrupt GoTo ISR_Handler

  Symbol RC522_PCD_IDLE       = 0x00
  Symbol RC522_PCD_AUTHENT    = 0x0E
  Symbol RC522_PCD_RECEIVE    = 0x08
  Symbol RC522_PCD_TRANSMIT   = 0x04
  Symbol RC522_PCD_TRANSCEIVE = 0x0C
  Symbol RC522_PCD_RESETPHASE = 0x0F
  Symbol RC522_PCD_CALCCRC    = 0x03

  Symbol RC522_PICC_REQIDL    = 0x26
  Symbol RC522_PICC_REQALL    = 0x52
  Symbol RC522_PICC_ANTICOLL_CL1  = 0x93
  Symbol RC522_PICC_ANTICOLL_CL2  = 0x95
  Symbol RC522_PICC_ANTICOLL_CL3  = 0x97

  Symbol RC522_PICC_SELECTTAG_CL1 = 0x93
  Symbol RC522_PICC_SELECTTAG_CL2 = 0x95
  Symbol RC522_PICC_SELECTTAG_CL3 = 0x97
  Symbol RC522_PICC_AUTHENT1A = 0x60
  Symbol RC522_PICC_AUTHENT1B = 0x61
  Symbol RC522_PICC_READ      = 0x30
  Symbol RC522_PICC_WRITE     = 0xA0
  Symbol RC522_PICC_DECREMENT = 0xC0
  Symbol RC522_PICC_INCREMENT = 0xC1
  Symbol RC522_PICC_RESTORE   = 0xC2
  Symbol RC522_PICC_TRANSFER  = 0xB0
  Symbol RC522_PICC_HALT      = 0x50  
  
  Symbol RC522_MI_OK          = 0
  Symbol RC522_MI_NOTAGERR    = 1
  Symbol RC522_MI_ERR         = 2

  Symbol RC522_Reg_Reserved00     = 0x00
  Symbol RC522_Reg_CommandReg     = 0x01
  Symbol RC522_Reg_ComIEnReg     = 0x02
  Symbol RC522_Reg_DivlEnReg      = 0x03
  Symbol RC522_Reg_ComIrqReg     = 0x04
  Symbol RC522_Reg_DivIrqReg      = 0x05
  Symbol RC522_Reg_ErrorReg       = 0x06
  Symbol RC522_Reg_Status1Reg     = 0x07
  Symbol RC522_Reg_Status2Reg     = 0x08
  Symbol RC522_Reg_FIFODataReg    = 0x09
  Symbol RC522_Reg_FIFOLevelReg   = 0x0A
  Symbol RC522_Reg_WaterLevelReg  = 0x0B
  Symbol RC522_Reg_ControlReg     = 0x0C
  Symbol RC522_Reg_BitFramingReg  = 0x0D
  Symbol RC522_Reg_CollReg        = 0x0E
  Symbol RC522_Reg_Reserved01     = 0x0F
  
  Symbol RC522_Reg_Reserved10     = 0x10
  Symbol RC522_Reg_ModeReg        = 0x11
  Symbol RC522_Reg_TxModeReg      = 0x12
  Symbol RC522_Reg_RxModeReg      = 0x13
  Symbol RC522_Reg_TxControlReg   = 0x14
  Symbol RC522_Reg_TxAutoReg      = 0x15
  Symbol RC522_Reg_TxSelReg       = 0x16
  Symbol RC522_Reg_RxSelReg       = 0x17
  Symbol RC522_Reg_RxThresholdReg = 0x18
  Symbol RC522_Reg_DemodReg       = 0x19
  Symbol RC522_Reg_Reserved11     = 0x1A
  Symbol RC522_Reg_Reserved12     = 0x1B
  Symbol RC522_Reg_MifareReg      = 0x1C
  Symbol RC522_Reg_Reserved13     = 0x1D
  Symbol RC522_Reg_Reserved14     = 0x1E
  Symbol RC522_Reg_SerialSpeedReg = 0x1F
  
  Symbol RC522_Reg_Reserved20        = 0x20  
  Symbol RC522_Reg_CRCResultRegM     = 0x21
  Symbol RC522_Reg_CRCResultRegL     = 0x22
  Symbol RC522_Reg_Reserved21        = 0x23
  Symbol RC522_Reg_ModWidthReg       = 0x24
  Symbol RC522_Reg_Reserved22        = 0x25
  Symbol RC522_Reg_RFCfgReg          = 0x26
  Symbol RC522_Reg_GsNReg            = 0x27
  Symbol RC522_Reg_CWGsPReg          = 0x28
  Symbol RC522_Reg_ModGsPReg         = 0x29
  Symbol RC522_Reg_TModeReg          = 0x2A
  Symbol RC522_Reg_TPrescalerReg     = 0x2B
  Symbol RC522_Reg_TReloadRegH       = 0x2C
  Symbol RC522_Reg_TReloadRegL       = 0x2D
  Symbol RC522_Reg_TCounterValueRegH = 0x2E
  Symbol RC522_Reg_TCounterValueRegL = 0x2F
  
  Symbol RC522_Reg_Reserved30      = 0x30
  Symbol RC522_Reg_TestSel1Reg     = 0x31
  Symbol RC522_Reg_TestSel2Reg     = 0x32
  Symbol RC522_Reg_TestPinEnReg    = 0x33
  Symbol RC522_Reg_TestPinValueReg = 0x34
  Symbol RC522_Reg_TestBusReg      = 0x35
  Symbol RC522_Reg_AutoTestReg     = 0x36
  Symbol RC522_Reg_VersionReg      = 0x37
  Symbol RC522_Reg_AnalogTestReg   = 0x38
  Symbol RC522_Reg_TestDAC1Reg     = 0x39
  Symbol RC522_Reg_TestDAC2Reg     = 0x3A
  Symbol RC522_Reg_TestADCReg      = 0x3B
  Symbol RC522_Reg_Reserved31      = 0x3C
  Symbol RC522_Reg_Reserved32      = 0x3D
  Symbol RC522_Reg_Reserved33      = 0x3E
  Symbol RC522_Reg_Reserved34      = 0x3F
    
  Symbol RC522_MaxLen = 100 ' was 20

  Symbol PICFirmwareVersion=18
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

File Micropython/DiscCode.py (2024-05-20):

import network
import utime
import ubinascii
import random
import json
import hashlib
import ntptime
from umqtt.simple import MQTTClient
from machine import deepsleep,UART,reset
import uos

import DiscFunctions

MACAddress=ubinascii.hexlify(network.WLAN(network.STA_IF).config('mac')).decode()

cfg=DiscFunctions.get_config()

srvbasekey=""
discbasekey=""
srvregkey=""


uos.dupterm(None,1)
uart = UART(0,115200,bits=8, parity=None, stop=1, timeout=2, timeout_char=2, rxbuf=255)
#uart.init(115200, bits=8, parity=None, stop=1, timeout=1, timeout_char=1)
#uart.init(115200, bits=8, parity=None, stop=1, timeout=2, timeout_char=2, rxbuf=256)
firmware_version="2.15"
uart.write(chr(13) + "PWRON" + chr(13))

def sub_cb(topic,msg):
    print("Received topic: " + str(topic))
    print("Payload: " + str(msg))
    if DiscFunctions.validate_message(topic,msg)==True:
        print("Valid message received")
        (t1,t2,t3,targetDisc,messageType)=topic.decode('utf-8').split('/')
        msgresult=DiscFunctions.process_message(messageType,msg,uart)
        if msgresult=="updatewifi":
            payload=json.loads(str(msg)[2:-65])
            uart.write("UPDWF" + chr(13))
            do_firmware_update(payload["files"],payload["urls"])
            uart.write("UPDOK" + chr(13))
            utime.sleep(1)
            reset()


def ser_check(mqttclient):
  global srvregkey
  global srvbasekey
  global discbasekey

  if (uart.any()):
    import ubinascii
    cmd=""
    serialline=uart.readline()
    #for a in serialline:
    #    print(str(a) + ",")
    cmd=cmd + serialline.decode("utf-8")
    #print("command: " + cmd)
    if len(cmd)>1:
        cmd=cmd.replace(chr(10),'').replace(chr(13),'')
        if (cmd[0]=='A' and mqttclient is not None):
            #voltageport=ADC(0)
            sta_if = network.WLAN(network.STA_IF)

            (picfirmware,batteryvoltage,diagresult)=cmd[1:].split(",")
            fwversion=firmware_version + " - " + DiscFunctions.get_dfversion()
            payloaddict={"discfirmware": fwversion , "discmicropython": uos.uname()[3], "picfirmware": picfirmware, "batteryvoltage": batteryvoltage, "wifivoltage": 0, "diagresult": diagresult, "network": str(sta_if.ifconfig()).replace("'",""), "timestamp": utime.time()}
            DiscFunctions.send_message(mqttclient,'/discs/from/' + MACAddress + '/alive',json.dumps(payloaddict))
            uart.write("CMDAK" + chr(13))
        if (cmd[0]=='B'):
            uart.write("PONGB" + chr(13))
        if (cmd[0]=='C' and mqttclient is not None):
            payloaddict={"cardtoken": cmd[1:], "timestamp": utime.time()}
            DiscFunctions.send_message(mqttclient,'/discs/from/' + MACAddress + '/capture',json.dumps(payloaddict))
        if (cmd[0]=='D' and mqttclient is not None):
            payloaddict={"debugmsg": cmd[1:], "timestamp": utime.time()}
            DiscFunctions.send_message(mqttclient,'/debug/from/' + MACAddress,json.dumps(payloaddict))
        if (cmd[0]=='E'):
            if DiscFunctions.have_keys():
                uart.write("HAVKY" + chr(13))
            else:
                uart.write("NOKEY" + chr(13))
        if (cmd[0]=='F' and mqttclient is not None):
            payloaddict={"batteryvoltage": cmd[1:], "timestamp": utime.time()}
            DiscFunctions.send_message(mqttclient,'/discs/from/' + MACAddress + '/flatbattery',json.dumps(payloaddict))
        if (cmd[0]=='H'):
            if (mqttclient is not None):
                payloaddict={"tamper": cmd[1:], "timestamp": utime.time()}
                DiscFunctions.send_message(mqttclient,'/discs/from/' + MACAddress + '/tamper',json.dumps(payloaddict))
                DiscFunctions.send_message(mqttclient,'/discs/from/' + MACAddress + '/wiped',json.dumps(payloaddict))
            DiscFunctions.wipe_config()
            mycfg=DiscFunctions.get_config()
            mycfg["tamper"]="active"
            DiscFunctions.save_config(mycfg)
            uart.write('WIPED' + chr(13))
            

        if (cmd[0]=='I' and mqttclient is not None):
            # commented out for dev
            #(srvregkey,srvbasekey,discbasekey)=cmd[1:].split(",")
            if len(srvregkey)==0 or len(srvbasekey)==0 or len(discbasekey)==0:
                uart.write("INITN" + chr(13))
            else:
                regresult=DiscFunctions.cmd_init(myclient,srvregkey,srvbasekey,discbasekey,MACAddress)
                if regresult!=0:
                    uart.write("INITS" + chr(13))
        if (cmd[0]=='J'):
            try:
                print("CFG: " + cmd[1:])
                (cfgitem,cfgvalue)=cmd[1:].split("\t")
                cfgitem=cfgitem.replace("text/","")
                if cfgitem=="regkey":
                    srvregkey=cfgvalue
                elif cfgitem=="srvkey":
                    srvbasekey=cfgvalue
                elif cfgitem=="disckey":
                    discbasekey=cfgvalue
                else:
                    mycfg=DiscFunctions.get_config()
                    mycfg[cfgitem]=cfgvalue
                    if "tamper" in mycfg:
                        mycfg["tamper"]=""
                    DiscFunctions.save_config(mycfg)
                uart.write("CMDAK" + chr(13))
            except Exception as inst:
                f=open("cfgupd-error.txt","w")
                f.write(inst.value)
                f.write(str(inst.errno))
                f.close()
        if (cmd[0]=='K'):
            uos.dupterm(UART(0, 115200), 1)
            import sys
            print("K command received")
            sys.exit()
        if (cmd[0]=='L'):
            payloaddict={"location": "", "timestamp": utime.time()}
            DiscFunctions.send_message(mqttclient,'/discs/from/' + MACAddress + '/location',json.dumps(payloaddict))
        if (cmd[0]=='N'):
           raise Exception('many','errors') 
        if (cmd[0]=='O'):
            payloaddict={"timestamp": utime.time()}
            DiscFunctions.send_message(mqttclient,'/discs/from/' + MACAddress + '/adminoffline',json.dumps(payloaddict))
        if (cmd[0]=='P'):
            print("Going to sleep")
            uart.write("SLEEP" + chr(13))
            deepsleep()
        if (cmd[0]=='Q' and mqttclient is not None):
            payloaddict={"query": cmd[1:], "timestamp": utime.time()}
            DiscFunctions.send_message(mqttclient,'/discs/from/' + MACAddress + '/query', json.dumps(payloaddict))
        if (cmd[0]=='R' and mqttclient is not None):
            (cardtoken,teamID,cardtype)=cmd[1:].split(",")
            payloaddict={"cardtoken": cardtoken, "teamID": teamID, "cardtype": cardtype, "timestamp": utime.time()}
            DiscFunctions.send_message(mqttclient,'/discs/from/' + MACAddress + '/register',json.dumps(payloaddict))
        if (cmd[0]=='S' and mqttclient is not None):
            payloaddict={"timestamp": utime.time()}
            DiscFunctions.send_message(mqttclient,'/discs/from/' + MACAddress + '/swap',json.dumps(payloaddict))
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

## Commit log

2024-05-20 Added 3D model
    [PolyGen Case Antenna Holder.stl, PolyGen Case Back Panel.stl, PolyGen Case Back URL.stl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]
2024-05-20 Initial code publication.
    [DiscAdventure-B_Cu.gbl, DiscAdventure-B_Mask.gbs, DiscAdventure-B_Paste.gbp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]
2026-02-17 Revise PCB Information with updates on components
    Updated PCB information to reflect component changes and availability issues.
2026-02-17 Update PCB Information with tamper detection details
    Added information about optional tamper detection switches and their configuration.
2026-02-17 Update PCB Information.txt
2026-02-17 Updated case design to 2025 version.
    [PolyGen Case Antenna Holder.stl, PolyGen Case Back Case ID 01.stl, PolyGen Case Back Panel.stl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]

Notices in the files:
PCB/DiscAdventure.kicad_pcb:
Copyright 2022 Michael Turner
